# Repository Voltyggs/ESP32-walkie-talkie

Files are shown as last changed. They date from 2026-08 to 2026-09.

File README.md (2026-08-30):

<h1>ESP TALK - the off grid solution to communication</h1>

ESP TALK is a walkie talkie based on the ESP32 and the ESPNOW protocol to provide a off gid communication medium

<br>


<h3>This is the schematic of my walkie talkie. The project consists of an esp32, mic, speaker, audio amplifier + DAC, and dual power supplies <br>
The i2s Mic first transmits its audio signals to the esp32 when the PTT button is held. After, the esp32 transmits the audio packets to the 0xFF, 0xFF, 0xFF, 0xFF, 0xFF, 0xFF address. The nearby walkie talkies pick up the signal and play it through the speaker which is powered by an MAX98351 which also doubles as a DAC for the esp32 for a better audio</h3>

- Main Features:
  - Completely self dependent and off grid as it runs with ESPNOW
  - antenna for a better range
  - uses the 12 bit DAC of the MAX98351 rather than the esp32's 8 bit DAC
Here is the case:

How to assemble: <br>
Pretty straight forward, place the assembled pcb in the base housing, glue the lid. There are 2 slots for 5.95 x 2.54 neodymium magnets that needs ot be glued onto the external lip. It can be used as a cvover for when the mic is not in use. <br>
<br>
How to use:<br>
**MAKE SURE TO PAY ATTENTION TO THE MIC ORIENTATION DURING ASSEMBLY AS IT MIGHT NEED TO BE FLIPPED AND MAKE SURE TO FLASH THE ESP32 BEFORE ASSEMBLY**<br>
This is a fairly simple project, after assembling it, charge the batteries through the TP4096 module (make sure to turn off the load switches), edit the transmit aaddress or keep it as default (0xFF, 0xFF, 0xFF, 0xFF, 0xFF, 0xFF). After that, just hold down teh push to talk button and transmit!

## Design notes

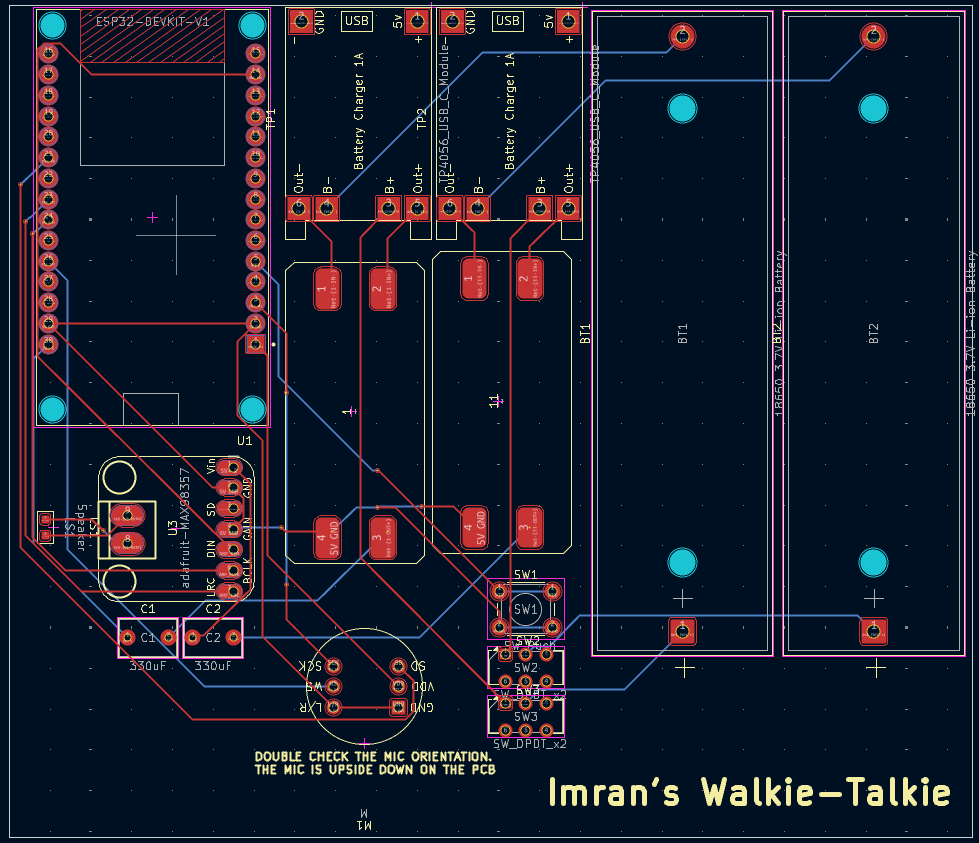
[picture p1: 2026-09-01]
Assets/PCB.png

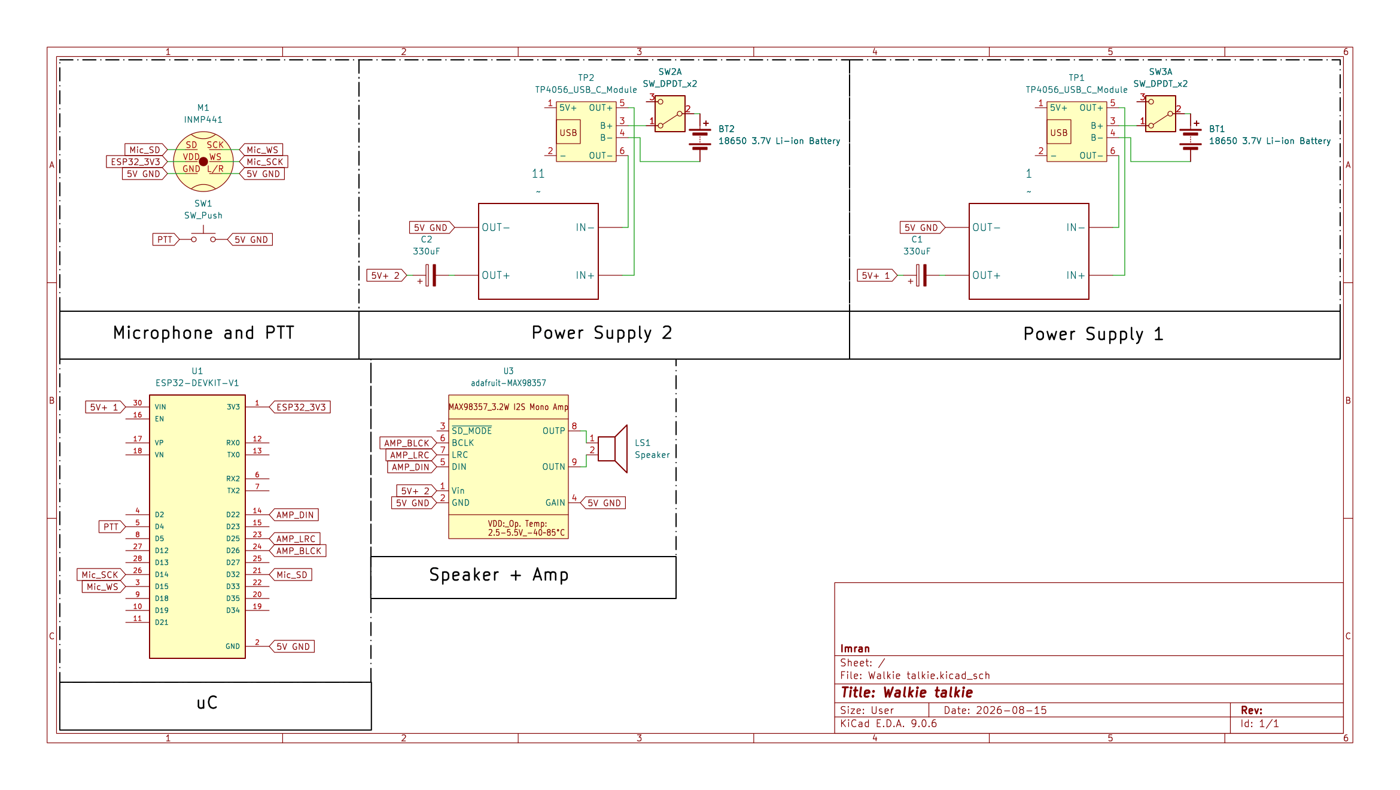
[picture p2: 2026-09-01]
Assets/Scehmatic.png

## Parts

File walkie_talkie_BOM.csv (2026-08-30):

# | Item Description | Quantity | Total Price (USD) | Aliexpress Link
1 | VEROBOARD DOT TYPE | 6 | 3 | https://www.aliexpress.com/item/1005012158303665.html?gatewayAdapt=4itemAdapt
2 | MT3608 2A MAX DC-DC STEP UP BOOSTER POWER MODULE | 5 (bundle) | 6 | https://www.aliexpress.com/item/1005012158271211.html?gatewayAdapt=4itemAdapt
3 | 18650 LITHIUM BATTERY CHARGER USB TYPE-C | 5 (bundle) | 4 | https://www.aliexpress.com/item/1005012023753266.html
4 | 18650 GENERIC 3.7V LI-ION BATTERY - BUTTON TOP | 4 | 11 | https://www.aliexpress.com/item/1005012946452793.html
5 | MALE TO MALE JUMPER WIRES 40 PIN 30CM | 2 | 8 | https://www.aliexpress.com/item/1005009741771008.html?gatewayAdapt=4itemAdapt
6 | 3 WATT 8 OHM MINI SPEAKER FOR ELECTRONICS PROJECT WITH JST-PH2.0 INTERFACE | 2 | 1 | https://www.aliexpress.com/item/1005005699690954.html
7 | MOMENTARY TACTILE PUSH BUTTON SWITCH 12 X 12MM X 12MM | 20 (bundle) | 6 | https://www.aliexpress.com/item/4000278832965.html?gatewayAdapt=4itemAdapt
8 | 2.4GHZ DUCK ANTENNA RP-SMA - 7.75 INCH MALE | 2 | 13 | https://www.aliexpress.com/item/32787855982.html?gatewayAdapt=4itemAdapt
9 | MAX98357A I2S DAC CLASS D MONO AMPLIFIER MODULE | 2 | 11 | https://www.aliexpress.com/item/3256810087074008.html
10 | ESP32 WROOM-32U CP2102 DEVELOPMENT BOARD MICRO USB | 2 | 19 | https://www.aliexpress.com/item/1005009640200327.html?gatewayAdapt=4itemAdapt
11 | INMP441 OMNIDIRECTIONAL MICROPHONE MODULE ORIGINAL | 2 | 2 | https://www.aliexpress.com/item/1005012438620524.html?gatewayAdapt=4itemAdapt
12 | 3300UF 16V ELECTROLYTIC CAPACITOR | 10 (bundle) | 1 | https://www.aliexpress.com/item/1005001627492009.html?gatewayAdapt=4itemAdapt
13 | RP-SMA TO U.FL ADAPTER RF CABLE - FEMALE 150MM | 2 (bundle) | 6 | https://www.aliexpress.com/item/1005009270045616.html?gatewayAdapt=4itemAdapt
14 | ROCKER SWITCH KCD11 ON/OFF SWITCH (MINI) RED | 2 | 5 | https://www.aliexpress.com/item/1005009323738855.html?gatewayAdapt=4itemAdapt
15 | SOLDER WIRE | 1 | 6 | https://www.aliexpress.com/item/1005008563576114.html
16 | 5MM RED LED (PACK OF 5) | 5 (bundle) | 2 | https://www.aliexpress.com/item/1005012080380940.html
GRAND TOTAL |  |  | 104

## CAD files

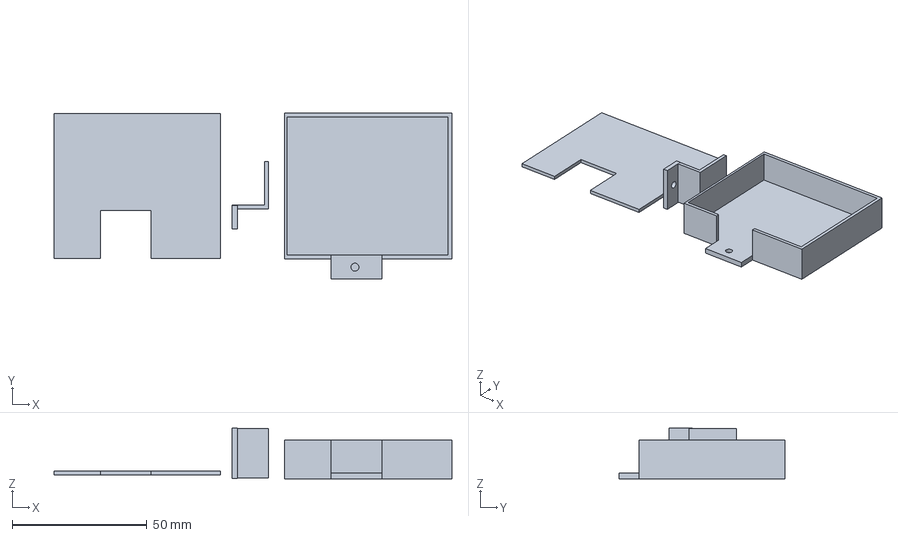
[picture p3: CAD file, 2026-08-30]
CAD/Walkie talkie case.3mf
147.8 x 61.7 x 18.8 mm

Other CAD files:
CAD/Walkie talkie case.obj

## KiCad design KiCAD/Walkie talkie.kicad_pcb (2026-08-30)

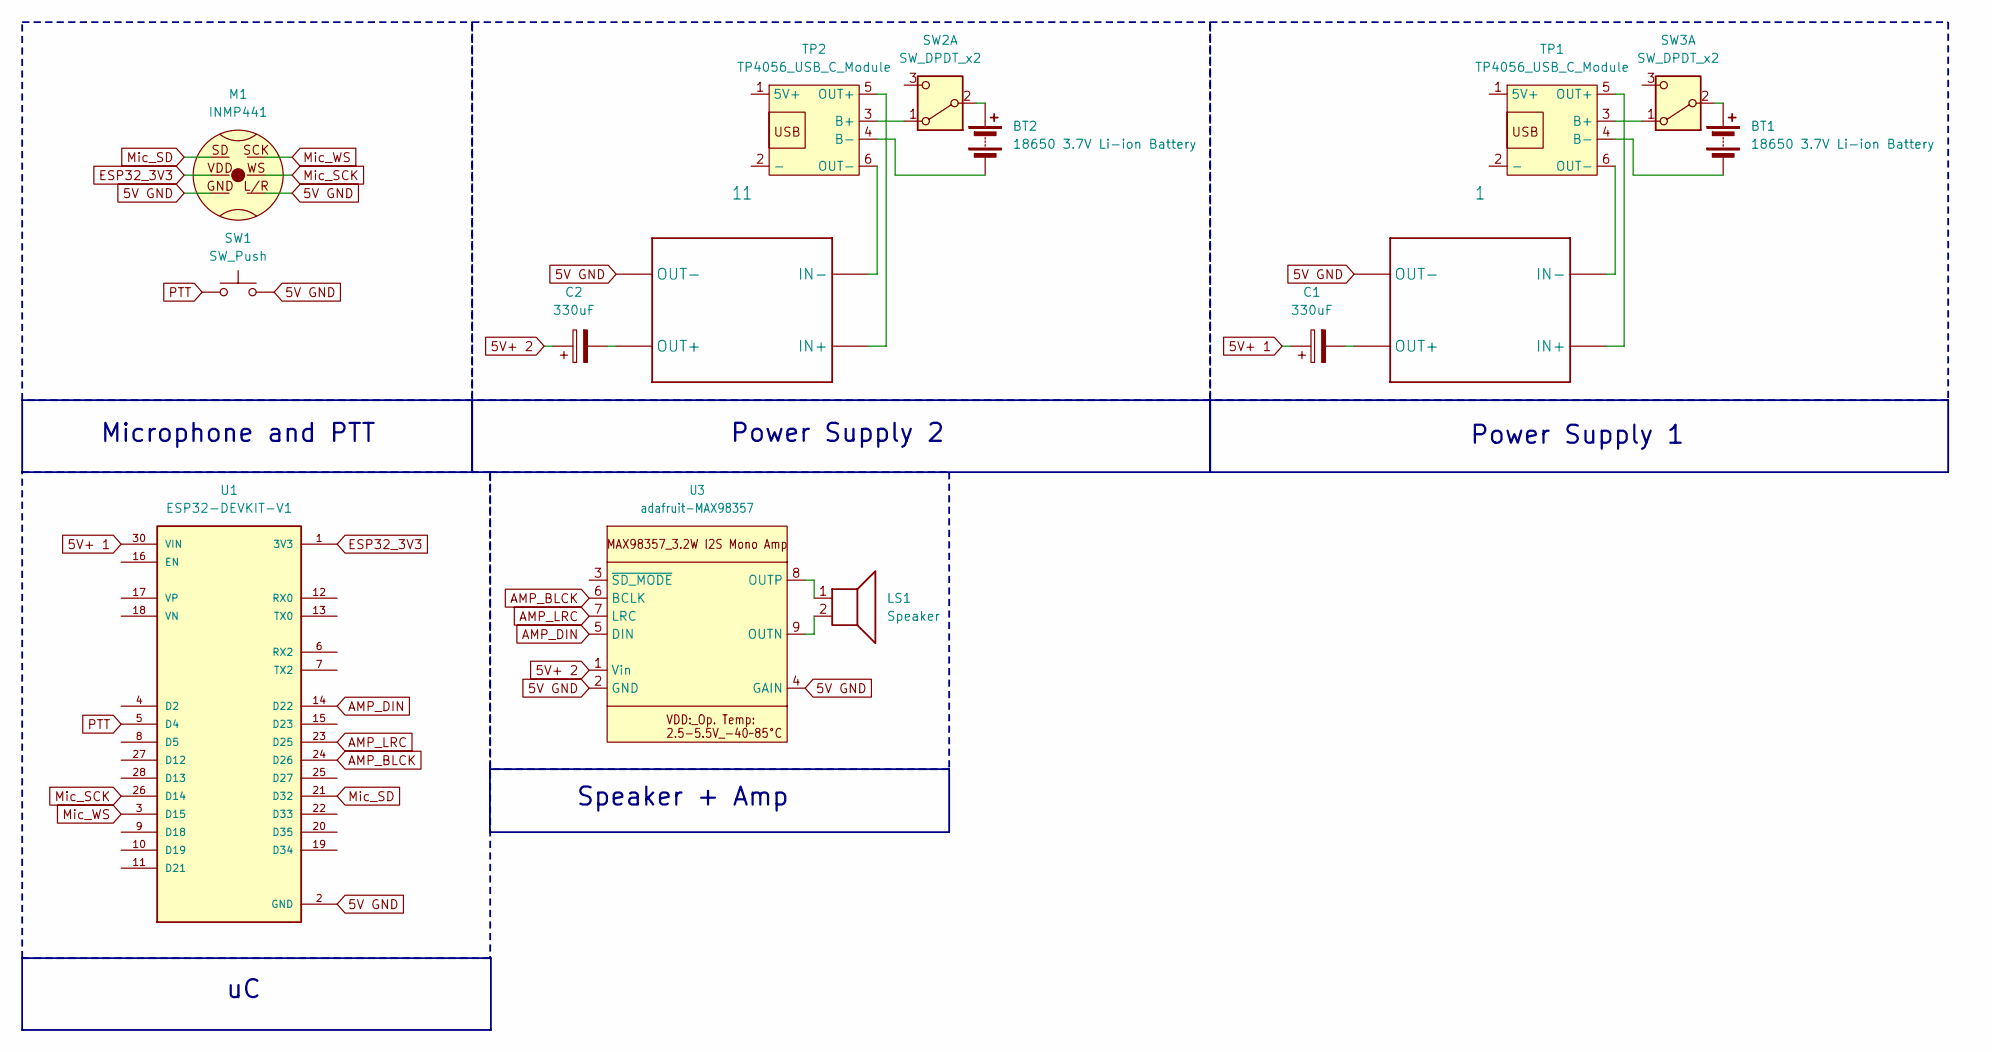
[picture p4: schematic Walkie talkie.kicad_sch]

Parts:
1, 11: hw-045
BT1, BT2: 18650 3.7V Li-ion Battery; BatteryHolder_MPD_BH-18650-PC
C1, C2: 330uF; C_Rect_L7.0mm_W4.5mm_P5.00mm
LS1: Speaker; 2_3W_8O_Speaker
M1: INMP441
SW1: SW_Push; SW_PUSH_6mm
SW2, SW3: SW_DPDT_x2; SW_CK_JS202011CQN_DPDT_Straight
TP1, TP2: TP4056_USB_C_Module; TP4056-18650
U1: ESP32-DEVKIT-V1; MODULE_ESP32_DEVKIT_V1; PARTREV N/A
U3: adafruit-MAX98357

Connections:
5V GND: 1.4 (OUT-), 11.4 (OUT-), M1.GND, M1.L/R, SW1.2, U1.2 (GND), U1.29 (GND), U3.2 (GND), U3.4 (GAIN)
5V+ 1: C1.1, U1.30 (VIN)
5V+ 2: C2.1, U3.1 (Vin)
AMP_BLCK: U1.24 (D26), U3.6 (BCLK)
AMP_DIN: U1.14 (D22), U3.5 (DIN)
AMP_LRC: U1.23 (D25), U3.7 (LRC)
ESP32_3V3: M1.VDD, U1.1 (3V3)
Mic_SCK: M1.WS, U1.26 (D14)
Mic_SD: M1.SD, U1.21 (D32)
Mic_WS: M1.SCK, U1.3 (D15)
unnamed: 1.2 (IN+), TP1.5 (OUT+)
unnamed: 1.1 (IN-), TP1.6 (OUT-)
unnamed: 1.3 (OUT+), C1.2
unnamed: 11.2 (IN+), TP2.5 (OUT+)
unnamed: 11.1 (IN-), TP2.6 (OUT-)
unnamed: 11.3 (OUT+), C2.2
unnamed: BT1.1 (+), SW3.2 (B)
unnamed: BT1.2 (-), TP1.4 (B-)
unnamed: BT2.1 (+), SW2.2 (B)
unnamed: BT2.2 (-), TP2.4 (B-)
unnamed: SW2.1 (A), TP2.3 (B+)
unnamed: SW3.1 (A), TP1.3 (B+)
unnamed: LS1.2, U3.9 (OUTN)
unnamed: LS1.1, U3.8 (OUTP)
PTT: SW1.1, U1.5 (D4)

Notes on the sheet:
Power Supply 2
Power Supply 1
Speaker + Amp
Microphone and PTT

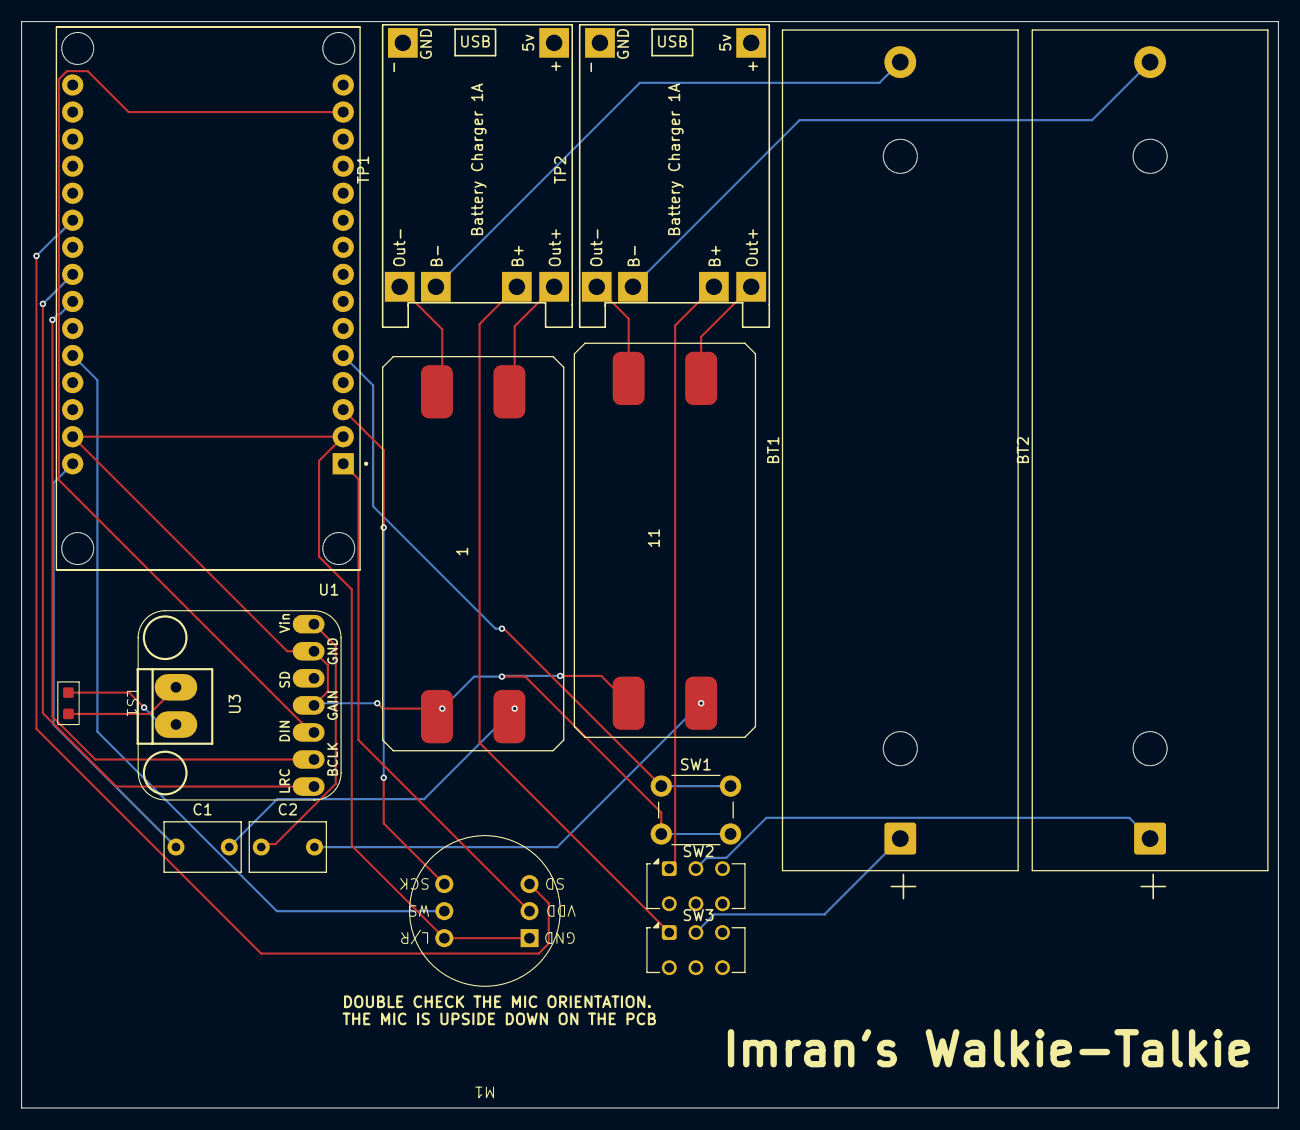
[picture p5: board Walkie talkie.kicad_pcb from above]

Board: 2 copper layers, 118.0 x 102.0 mm, 15 parts (0 on the bottom side), 25 nets.

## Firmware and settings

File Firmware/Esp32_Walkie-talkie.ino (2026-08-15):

#include <WiFi.h>
#include <esp_now.h>
#include <esp_wifi.h>
#include <driver/i2s.h>

#define PTT_PIN 4
#define MIC_SCK_PIN 14  
#define MIC_WS_PIN 33
#define MIC_SD_PIN 32
#define AMP_BCLK_PIN 26  
#define AMP_LRC_PIN 27  
#define AMP_DIN_PIN 25

#define SAMPLE_RATE 16000
#define BUFFER_SIZE 200 

uint8_t txBuffer[BUFFER_SIZE];
uint8_t broadcastAddress[] = {0xFF, 0xFF, 0xFF, 0xFF, 0xFF, 0xFF};

bool isTransmitting = false;




void OnDataRecv(const uint8_t * mac, const uint8_t *incomingData, int len) {
  if (digitalRead(PTT_PIN) == HIGH) {
    size_t bytesWritten = 0;
    i2s_write(I2S_NUM_1, incomingData, len, &bytesWritten, portMAX_DELAY);
  }
}

void initI2S() {
  i2s_config_t micConfig = {
    .mode = (i2s_mode_t)(I2S_MODE_MASTER | I2S_MODE_RX),
    .sample_rate = SAMPLE_RATE,
    .bits_per_sample = I2S_BITS_PER_SAMPLE_16BIT,
    .channel_format = I2S_CHANNEL_FMT_ONLY_LEFT,
    .communication_format = I2S_COMM_FORMAT_STAND_I2S,
    .intr_alloc_flags = ESP_INTR_FLAG_LEVEL1,
    .dma_buf_count = 4,
    .dma_buf_len = 100,
    .use_apll = false
  };

  i2s_pin_config_t micPins = {
    .bck_io_num = MIC_SCK_PIN,
    .ws_io_num = MIC_WS_PIN,
    .data_out_num = I2S_PIN_NO_CHANGE,
    .data_in_num = MIC_SD_PIN
  };

  i2s_driver_install(I2S_NUM_0, &micConfig, 0, NULL);
  i2s_set_pin(I2S_NUM_0, &micPins);

  i2s_config_t ampConfig = {
    .mode = (i2s_mode_t)(I2S_MODE_MASTER | I2S_MODE_TX),
    .sample_rate = SAMPLE_RATE,
    .bits_per_sample = I2S_BITS_PER_SAMPLE_16BIT,
    .channel_format = I2S_CHANNEL_FMT_ONLY_LEFT,
    .communication_format = I2S_COMM_FORMAT_STAND_I2S,
    .intr_alloc_flags = ESP_INTR_FLAG_LEVEL1,
    .dma_buf_count = 4,
    .dma_buf_len = 100,
    .use_apll = false
  };

  i2s_pin_config_t ampPins = {
    .bck_io_num = AMP_BCLK_PIN,
    .ws_io_num = AMP_LRC_PIN,
    .data_out_num = AMP_DIN_PIN,
    .data_in_num = I2S_PIN_NO_CHANGE
  };

  i2s_driver_install(I2S_NUM_1, &ampConfig, 0, NULL);
  i2s_set_pin(I2S_NUM_1, &ampPins);
}

void setup() {
  Serial.begin(115200);
  Serial.println("Booting");
  pinMode(PTT_PIN, INPUT_PULLUP);
  
  initI2S();
  Serial.println("Audio ok");

  WiFi.mode(WIFI_STA);
  esp_wifi_set_protocol(WIFI_IF_STA, WIFI_PROTOCOL_LR);

  if (esp_now_init() != ESP_OK) {
    Serial.println("espnoW error.");
    return;
  }
  
  esp_now_register_recv_cb(esp_now_recv_cb_t(OnDataRecv));
  esp_now_peer_info_t peerInfo = {};
  memcpy(peerInfo.peer_addr, broadcastAddress, 6);
  peerInfo.channel = 0;  
  peerInfo.encrypt = false;
  
  if (esp_now_add_peer(&peerInfo) != ESP_OK) {
    Serial.println("Failed to register broadcast channel");
    return;
  }
}

void loop() {
  bool buttonPressed = (digitalRead(PTT_PIN) == LOW);
  if (buttonPressed && !isTransmitting) {
    Serial.println("Mic open");
    isTransmitting = true;
  } 
  else if (!buttonPressed && isTransmitting) {
    Serial.println("mic closed");
    isTransmitting = false;
  }

  if (buttonPressed) {
    size_t bytesRead = 0;

    i2s_read(I2S_NUM_0, txBuffer, BUFFER_SIZE, &bytesRead, portMAX_DELAY);
    
    if (bytesRead > 0) {
      esp_now_send(broadcastAddress, txBuffer, bytesRead);
    }
  }
}

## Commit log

2026-08-15 Add temp file to KiCAD directory
2026-08-15 Enhance README with project details and setup instructions
    Expanded project description and details about hardware components, architecture, power delivery, and setup instructions.
2026-08-26 Enhance README with battery charging instructions
    Updated usage instructions to include battery charging details.
2026-08-26 Update usage instructions in README
    Added a warning about microphone orientation during assembly and improved instructions for usage.
2026-09-01 Create KiCAD
